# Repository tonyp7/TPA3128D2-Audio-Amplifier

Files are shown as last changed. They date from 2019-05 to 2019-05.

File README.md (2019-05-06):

# TPA3128D2-Audio-Amplifier
A simple PCB for Texas Instrument's TPA3128D2 Stereo, 2x30W Class-D Amplifier

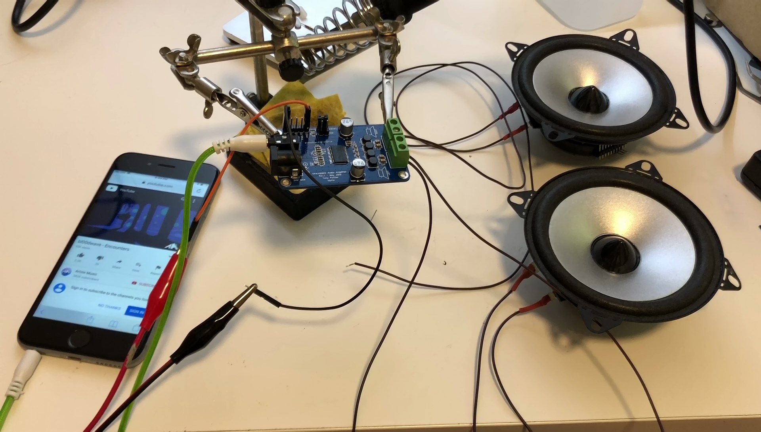
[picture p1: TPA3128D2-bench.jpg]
Audio Amp


# Schematics
Schematics are availble in their original source file format (Dip Trace) as well as PNG.

# PCB
PCB is availble in its original file format (Dip Trace) alongside exported Gerbers.
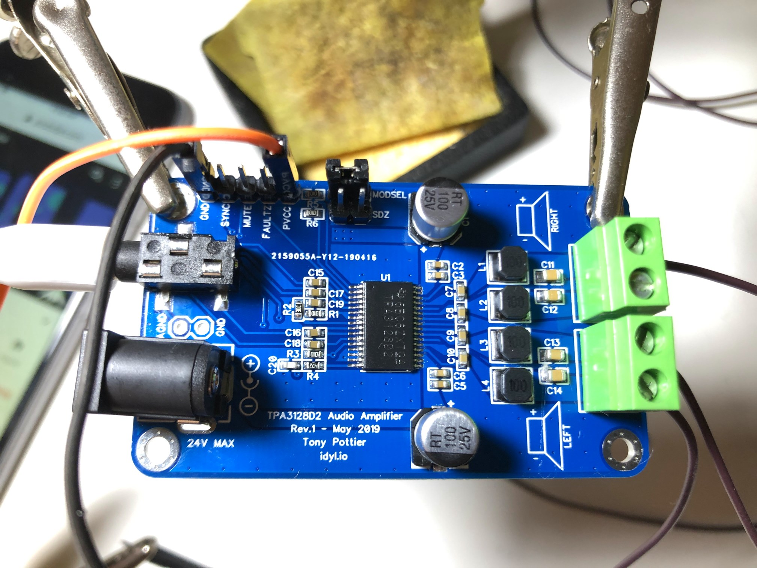
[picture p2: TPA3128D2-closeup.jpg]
Board Close up


# BoM
BoM is available as a CSV file. All parts should be easy to source. The audio jack might be tricky because there are just SO MANY different footprints for audio jacks out there! I used a PJ-320B which is the typical cheap jack you see on Chinese gizmos. It works pretty well.

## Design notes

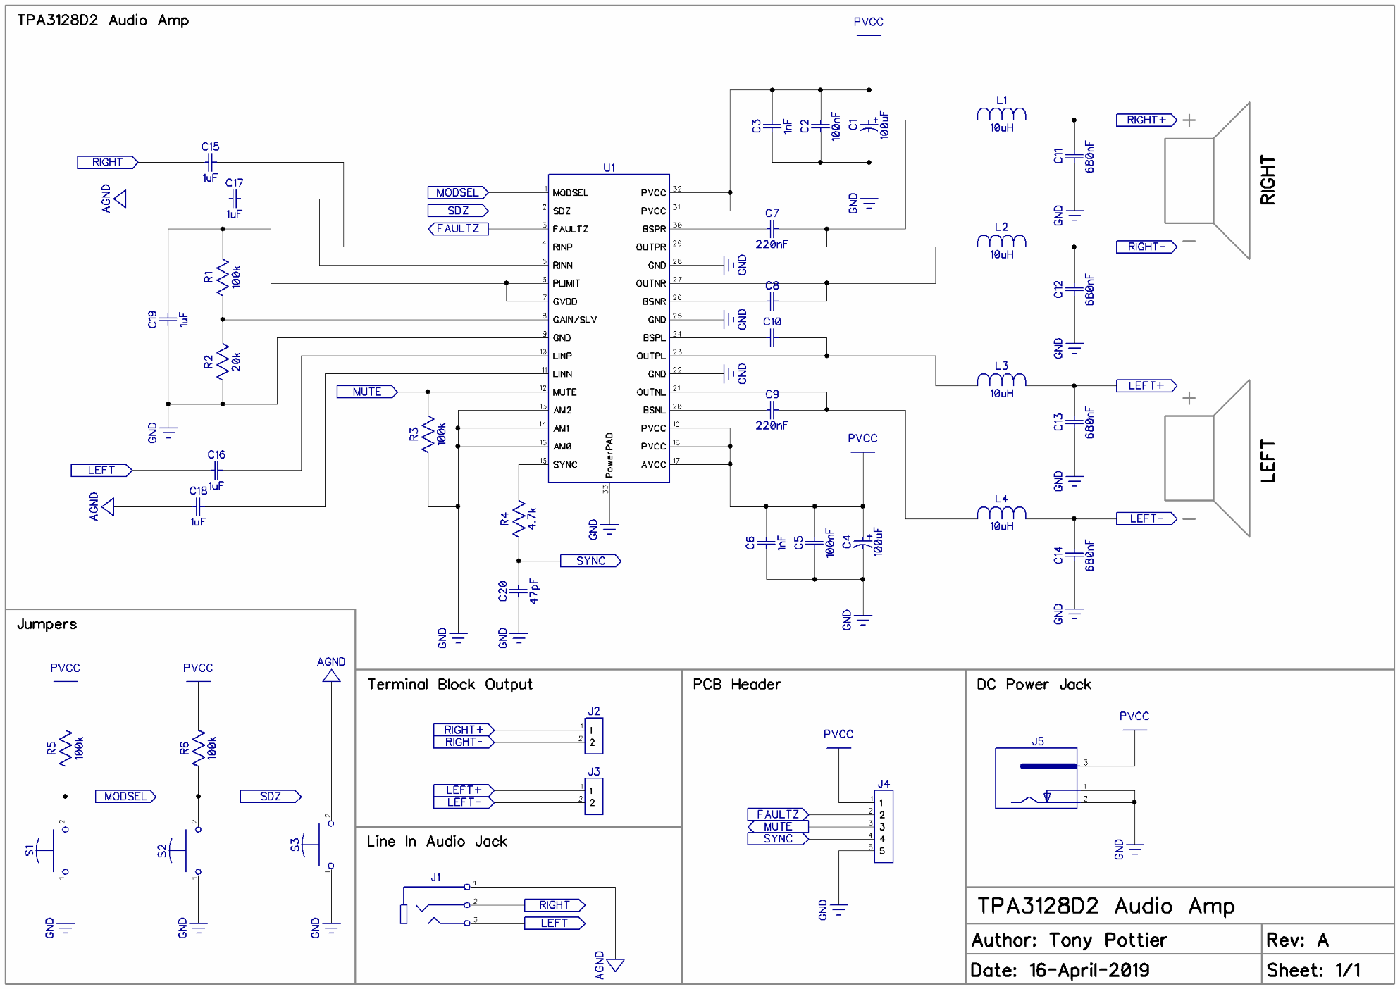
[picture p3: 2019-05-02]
schematics/TPA3121D2.png

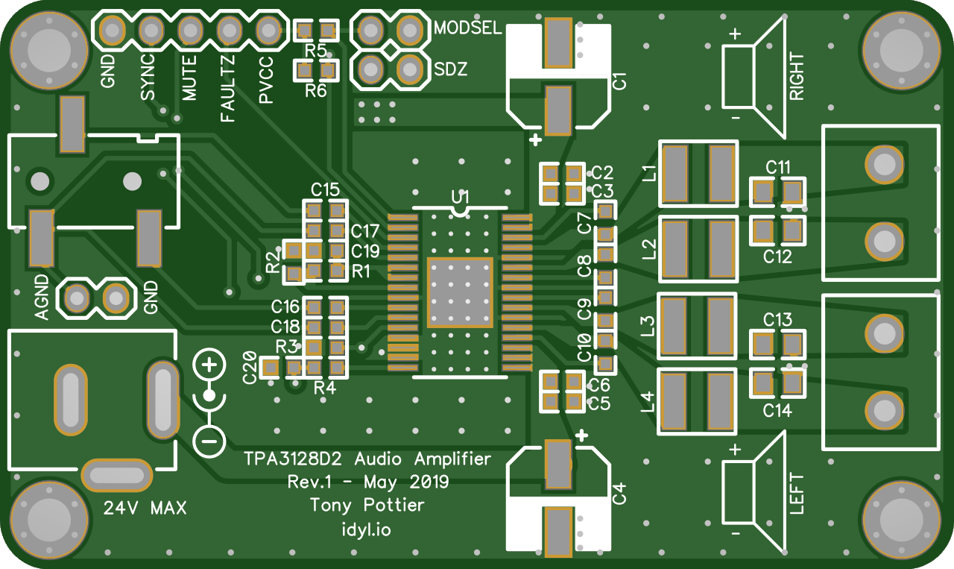
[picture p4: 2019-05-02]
pcb/TPA3121D2-top-render.png

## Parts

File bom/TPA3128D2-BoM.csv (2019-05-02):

RefDes | Description | Manufacturer | Quantity | Manufacturer Part Number | Comment
C1, C4 | 100uF, 6.3x7.7 | ROQANG | 2 | RT1E101M0607 | Any 6mm SMT cap will work
C2, C5 | 100nF, 0603, X7R, 50V | Yageo | 2 | CC0603KRX7R9BB104
C3, C6 | 1nF, 0603, X7R, 50V | Yageo | 2 | CC0603KRX7R9BB102
C7, C8, C9, C10 | 220nF, 0603, X7R, 50V | Yageo | 4 | CC0603KRX7R9BB224
C11, C12, C13, C14 | 680nF, 0805, X7R, 50V | Yageo | 4 | CC0805KKX7R9BB684
C15, C16, C17, C18, C19 | 1uF, 0603, X7R, 16V | Samsung Electro-Mechanics | 5 | CL10B105KO8NNNC
C20 | 47pF, 0603, NP0, 50V | Yageo | 1 | CC0603JRNPO9BN470
J1 | Audio Jack Connector | Boom Precision Elec | 1 | PJ-320B
J2, J3 | Terminal Block, 5mm | Ningbo Kangnex Elec | 2 | WJ301V-5.0-2P | Any 5mm block will work, such as Multicomp MC24356-2.
J5 | DC Jack, 2mm | Boom Precision Elec | 1 | DC-005 5.5-2.0MM | This a standard through-hole DC jack such as the ones you can find on Arduinos.
L1, L2, L3, L4 | 10uH | Cenker | 4 | CKCS4030-10uH/M | Inductors in standard 4mm footprint will work.See: Bourns SRP4020 series, Abracon ASPI-4030 series, Wurth Electronics LQS 4025 series
R1, R3, R5, R6 | 100k, 0603, 1%, 1/10W | Yageo | 4 | RC0603FR-07100KL
R2 | 20k, 0603, 1%, 1/10W | Yageo | 1 | RC0603FR-0720KL
R4 | 4.7k, 0603, 1%, 1/10W | Yageo | 1 | RC0603FR-074K7L
U1 | TPA3128D2 | Texas Instruments | 1 | TPA3128D2DAPR

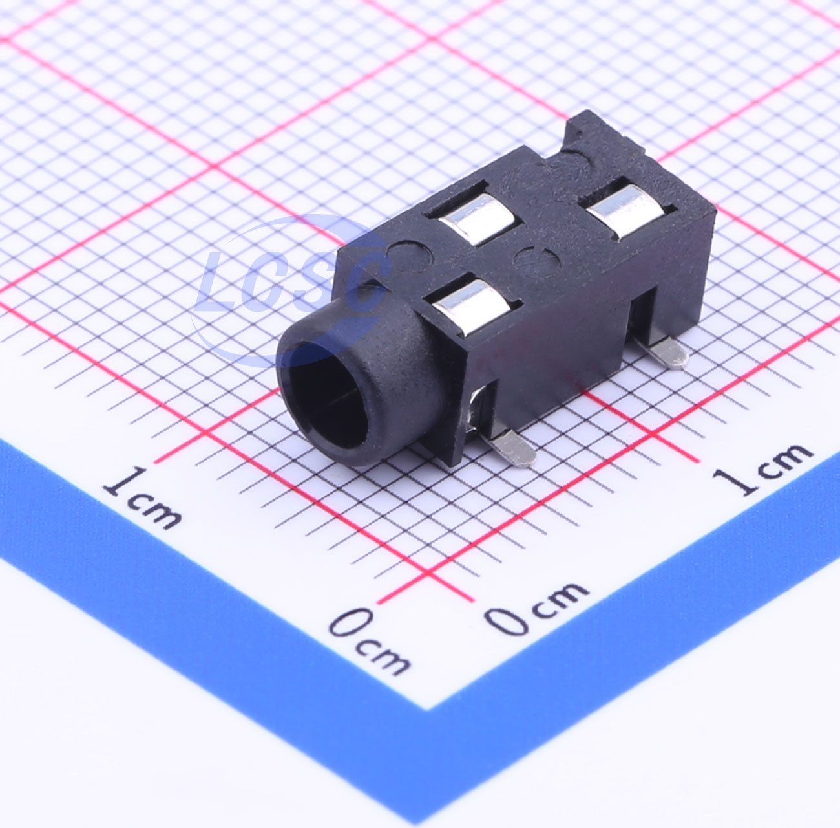
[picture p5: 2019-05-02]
bom/audio-jack-lcsc.jpg

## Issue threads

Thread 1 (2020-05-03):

TAS5805M format

tjacobs, 2020-05-03:
Hi Tony, sorry I couldn't find your email anywhere.

I'm using a TAS5805M, based on your recommendation of it, and all I'm getting is a big click sound from it.

I'm driving it with an ESP32-WROVER. I set it to 16-bit I2S, and play mode, and send it 16-bit I2S data, from https://github.com/earlephilhower/ESP8266Audio/blob/master/src/AudioOutputI2S.cpp#L61, but still just the speaker pops out for the duration of the sample, then returns. BTL mode. 13V. With ferrite filters. It can detect the chip via I2C just fine.

And I've driven an I2S DAC chip with the same code and heard audio just fine before:
https://datasheets.maximintegrated.com/en/ds/MAX98357A-MAX98357B.pdf

I set the TAS5805M up with:
```
  i2c_write(0x2F, 3, 2); // Hi Z
  delay(10);
  i2c_write(0x2F, 0x33, 3); // 16-bit I2S
  delay(10);
  i2c_write(0x2F, 3, 3); // Play
```
Any ideas? Do you have any example code snippet to set it up?

Thanks,
Tom

tonyp7, 2020-05-04:
This is not the right audio amp, I think you mean this one:

https://idyl.io/tas5805m-audio-amplifier-showcase/

I didnt publish PCB and code for this one and I can't find it back unfortunately. I don't remember you had to fiddle with the I2S setup though, just feed the codec I2S and good to go.

I used https://github.com/espressif/esp-idf/tree/master/examples/bluetooth/bluedroid/classic_bt/a2dp_sink for a BT player

tjacobs, 2020-05-05:
Thanks for the reply - yes that seems to output I2S the same way I am:
https://github.com/espressif/esp-idf/blob/master/examples/bluetooth/bluedroid/classic_bt/a2dp_sink/main/main.c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

I tried specifying 32-BLKs per frame via I2C as well, that didn't help either.

It still just either pops, or makes a high pitched buzzing sound on power-on. With two different chips.

Maybe something basic is wrong with the schematic? I based it on the ferrite example application schematic.

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

```
  out = new AudioOutputI2S();
  out->SetPinout(14, 27, 12); // int bclk, int wclk, int dout)
```

tonyp7, 2020-05-05:
I found the design file -- this is the layout I used

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

Somehow I doubt having the ferrite bead and not grounding the bottom pad would lead to no sound at all, but I am not sure :(

tonyp7, 2020-05-05:
You know what I saw that TI just released a newer revision (TAS5806M). I'll build a board and publish it properly this time :)

tjacobs, 2020-05-07:
Thanks, still no sound. Tried a different data pin, still no sound. :(

tonyp7, 2020-05-08:
I found this interesting tidbit in the datasheet that might explains your issues:

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

In the meantime I have created https://github.com/tonyp7/TAS5806M-Audio-Amplifier and have sent the board for manufacturing.

tjacobs, 2020-05-09:
Nice! Would love to buy one of these from you if you have one available!

tonyp7, 2020-05-10:
I wouldn’t recommend it. This is an older chip that requires more components which have now been integrated in the 05M/06M and might be even more finicky to setup.

The 06M has no more MCLK input for instance, and that’s a strong proof that TI is simplifying their designs to their best of their abilities.

I’ve bought enough components to make 3 boards so I’ll be happy to ship one over to you if it works and everything comes through well enough!

tonyp7, 2020-05-16:
I received the PCBs today -- [assembled one board and it's working!](https://gfycat.com/repentantgrossanteater)

Btw I confirm that I'm just doing this:

`			ESP_LOGI("I2C", "Setting to HI Z");
			ESP_ERROR_CHECK(tas5806m_write_byte(0x03, 0x02));
			vTaskDelay(100 / portTICK_RATE_MS);
			ESP_LOGI("I2C", "Setting to PLAY");
			ESP_ERROR_CHECK(tas5806m_write_byte(0x03, 0x03));`

There's nothing else on the I2C part, don't try to manually setup clocks and format, the chip should autodetect. I had no sound at first but I checked registered 70h and it read 0x04 clock fault. I changed the crappy jumper wires for proper wire wrapping and it worked like a charm! Maybe if you're using jumper they could be the cause of your issue.

Another thing is that there is a bit of code involved to make sure I setup the chip only after I2S is stable, as TI recommends. So there's a mutex that gets released once the sound starts, and that triggers the I2C setup.

I need to clean up the code but I'll upload it once it's less of a proof of concept mess.

tjacobs, 2020-05-17:
Wow! I finally got it working!

It turns out I think the ESP32 wasn't connected to wifi, so loop() was never running. So silly.

tonyp7, 2020-05-17:
Great to hear; it's an amazing amp ;-)

I'm closing this issue and you can follow https://github.com/tonyp7/TAS5806M-Audio-Amplifier/ for further progress!

Closed 2020-05-17.
